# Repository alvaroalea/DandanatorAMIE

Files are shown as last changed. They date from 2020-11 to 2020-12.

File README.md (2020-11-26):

# ZX Dandanator with Multiply Addon all in one
## Alea's Multiply Integrated Edition

UNDER LICENSE Creative Commons Attribution-NonCommercial-ShareAlike 4.0 International (CC BY-NC-SA 4.0)
- If you remix, transform, or build upon the material, you must distribute your contributions under the same license as the original.
- You may not use the material for commercial purposes.
- You must give appropriate credit, provide a link to the license, and indicate if changes were made. You may do so in any reasonable manner, but not in any way that suggests the licensor endorses you or your use.

Original Design by Dandare, mad3001 and OverClk

PCB Design of the V2.1AMIE edition by AlvaroAlea

This is a project to integrate in only one PCB (well, in three) the ZX Dandanator Cartridge for ZX Spectrum and the Multiply Addon.

Check the father projects:

http://www.dandare.es

https://github.com/mad3001/Multiply

Your can download the programs need for programing GAL & PIC on this links

## Features

* 512Kb of flash memory for zero seconds load of games with a fancy menu

* microSD Card Slot for load of snapshots (Z80 and SNA) and tape files, also to program the flash memory

* microUSB conection for transfer flash memory from PC to Dandanator

* A multi-protocol Joystick conector that provide a Kempston Interface and allow to use any atari, SJS, or megadrive joystick with any ZX Spectrum

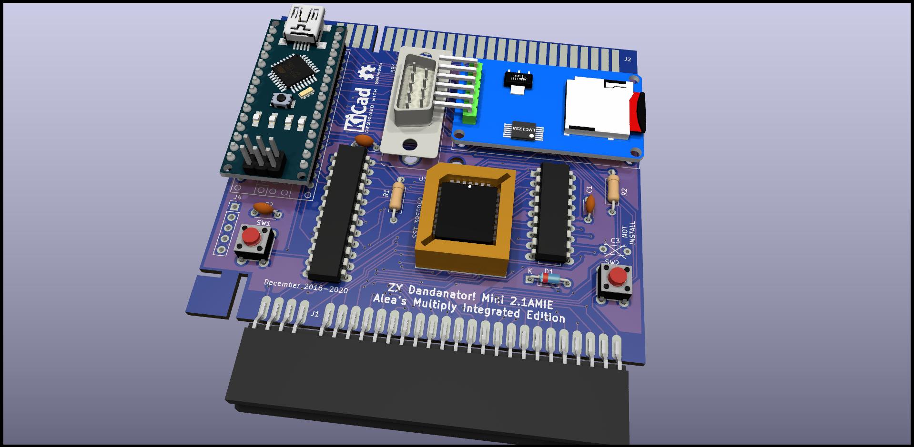
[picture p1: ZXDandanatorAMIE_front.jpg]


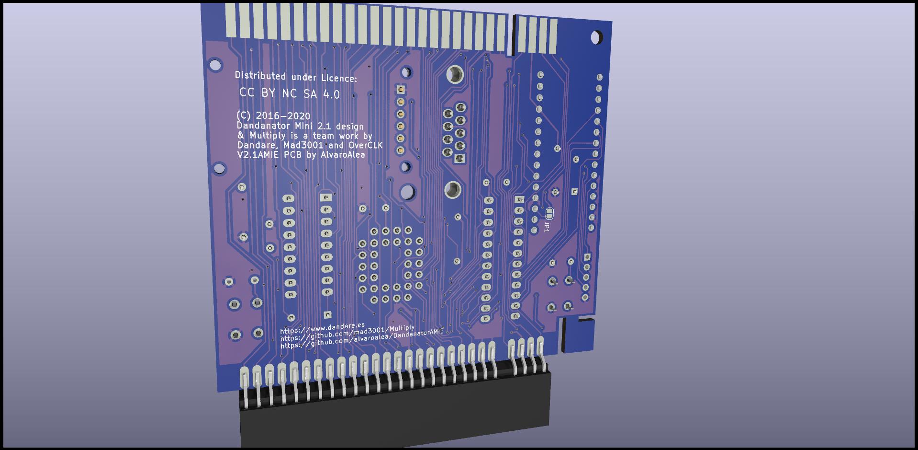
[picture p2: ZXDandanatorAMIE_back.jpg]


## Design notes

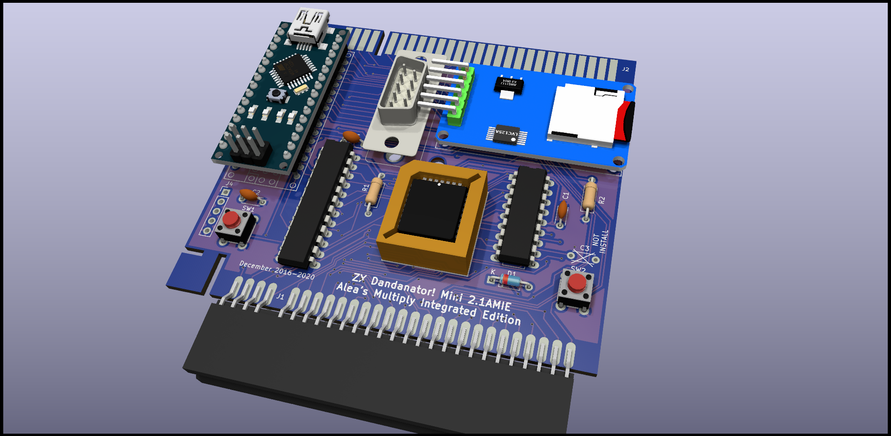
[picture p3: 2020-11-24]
ZX Dandanator Mini 2.1b.png

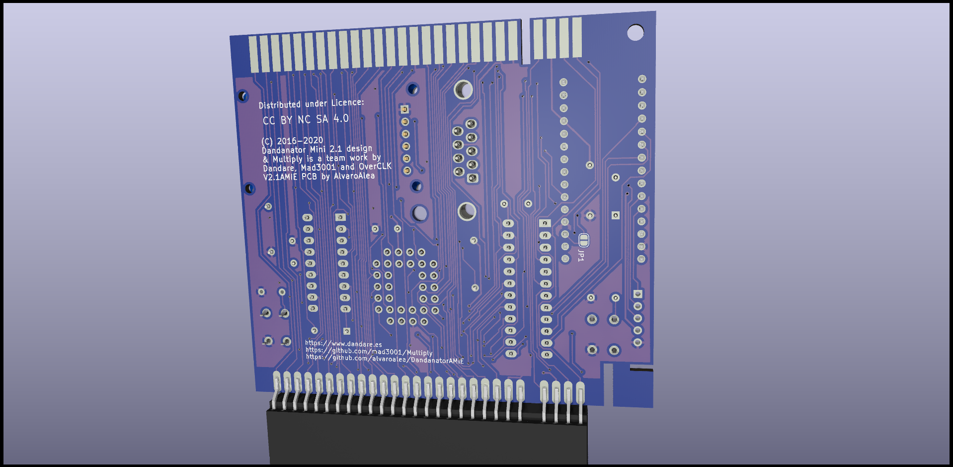
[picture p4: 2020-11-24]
ZX Dandanator Mini 2.1b_back.png

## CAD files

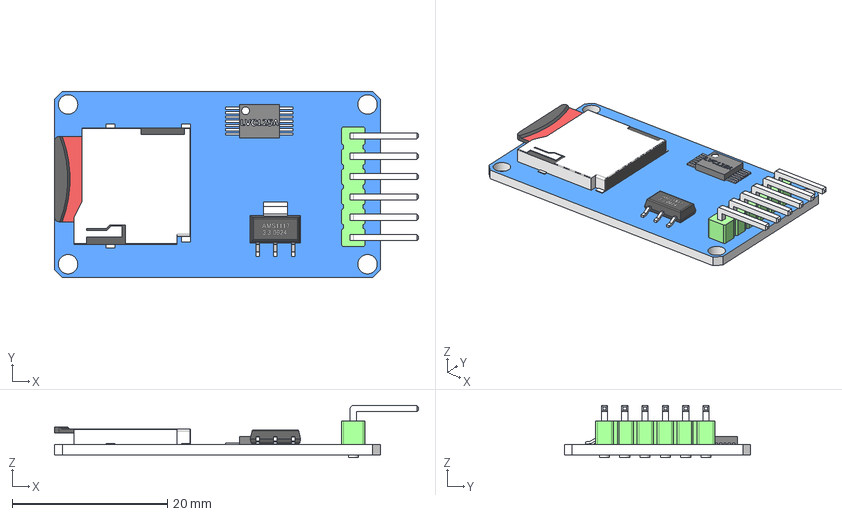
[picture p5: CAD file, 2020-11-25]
MicroSD Reader Assembly.stp
46.9 x 24.0 x 6.70 mm
sdreader
AMS1117
card sd

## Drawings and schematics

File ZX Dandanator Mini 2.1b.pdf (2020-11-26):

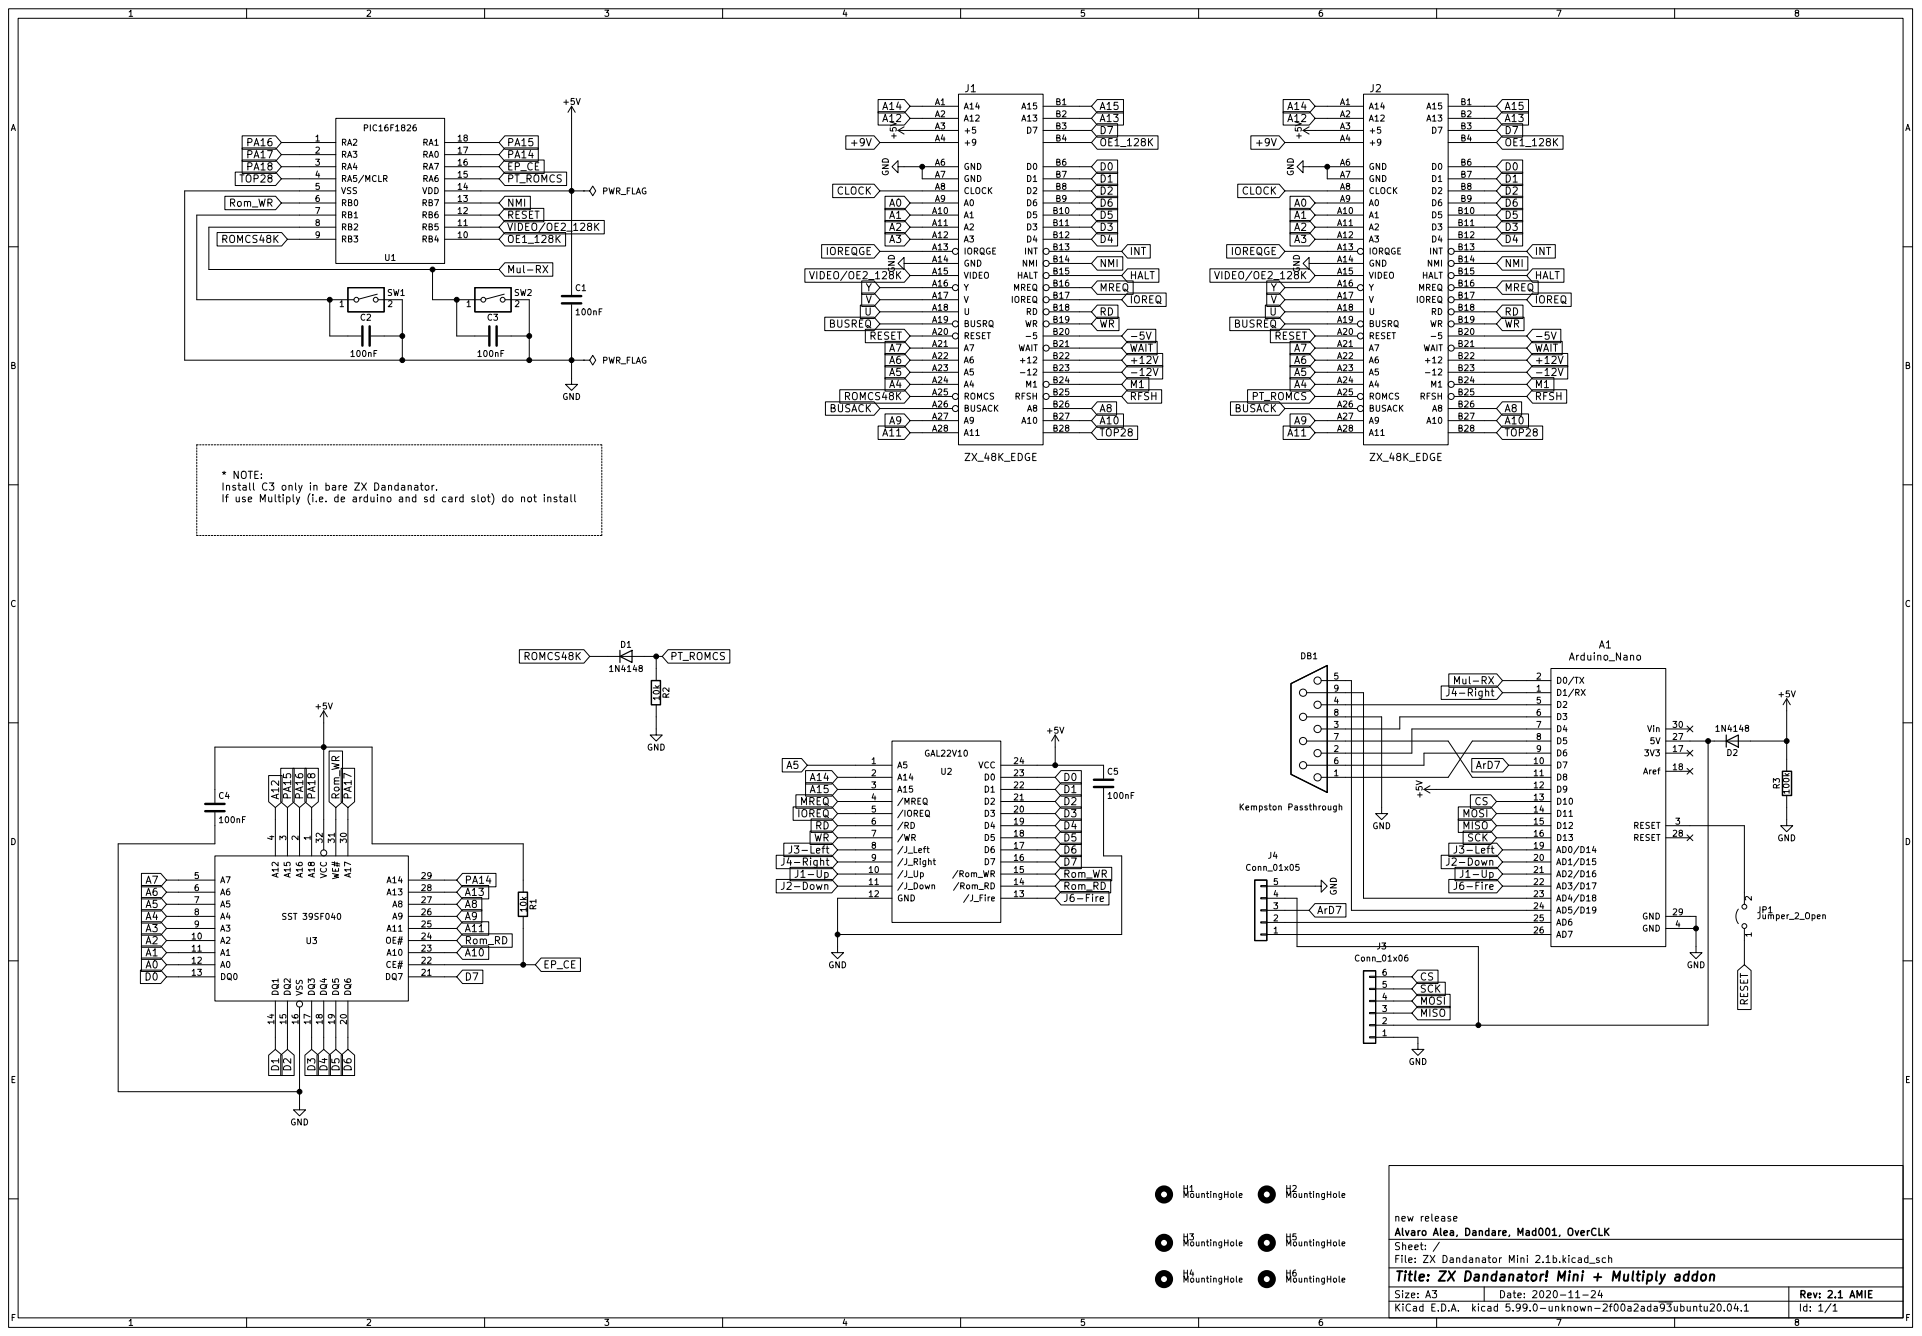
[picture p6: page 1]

4 U3 SST 39SF040 +5V GND GND GND 10k R1 GND +5V

* NOTE:
Install C3 only in bare ZX Dandanator.
If use Multiply (i.e. de arduino and sd card slot) do not install

new release
File: ZX Dandanator Mini 2.1b.kicad_sch Sheet: / Alvaro Alea, Dandare, Mad001, OverCLK

Id: 1/1 Title: ZX Dandanator! Mini + Multiply addon

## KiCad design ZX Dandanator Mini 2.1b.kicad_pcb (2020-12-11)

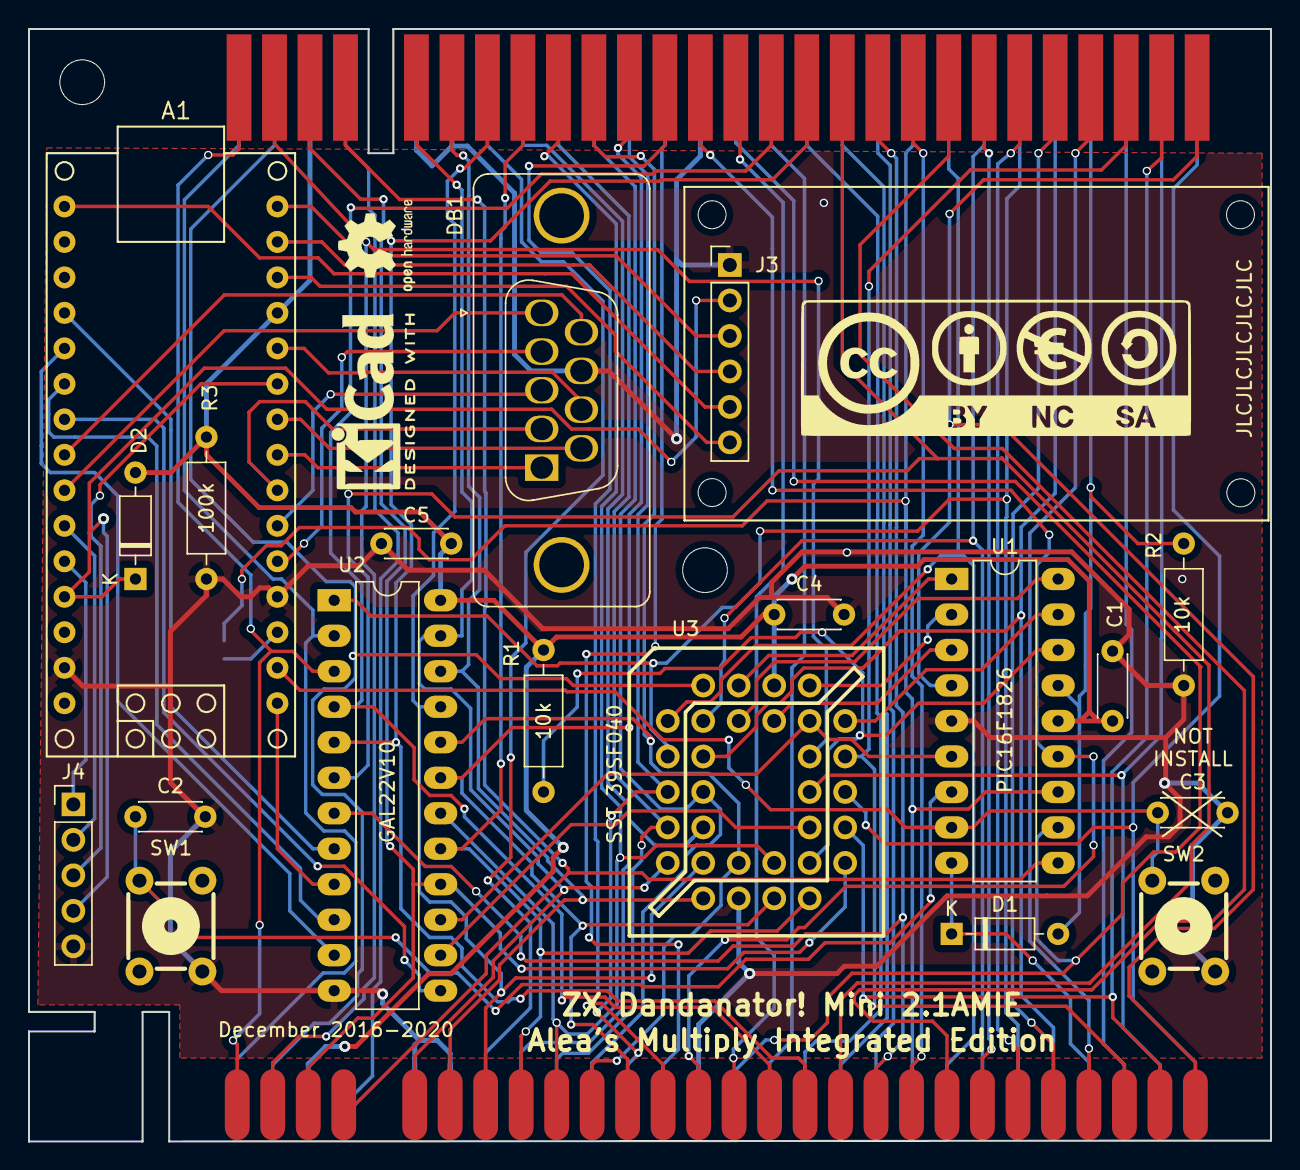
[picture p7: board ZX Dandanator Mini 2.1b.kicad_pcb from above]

Board: 2 copper layers, 88.9 x 79.6 mm, 28 parts (1 on the bottom side), 85 nets.

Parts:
A1: Arduino_Nano; arduino_nano
C1, C2, C3, C4, C5: 100nf; C_Disc_D4.3mm_W1.9mm_P5.00mm
D1, D2: 1n4148; D_DO-35_SOD27_P7.62mm_Horizontal
DB1: Kempston Passthrough; DSUB-9_Female_Vertical_P2.77x2.84mm_MountingHoles
H1, H2: MountingHole; MountingHole_3.2mm_M3_ISO7380
H3, H4, H5, H6: MountingHole; MountingHole_2mm
J1: ZX_48K_EDGE; ZX_CONN
J2: ZX_48K_EDGE; ZX_BUS
J3: Conn_01x06; PinHeader_1x06_P2.54mm_Vertical
J4: Conn_01x05; PinHeader_1x05_P2.54mm_Vertical
JP1: Jumper_2_Open; SolderJumper-2_P1.3mm_Open_RoundedPad1.0x1.5mm
R1, R2: 10k; R_Axial_DIN0207_L6.3mm_D2.5mm_P10.16mm_Horizontal
R3: 100k; R_Axial_DIN0207_L6.3mm_D2.5mm_P10.16mm_Horizontal
SW1, SW2: SW_PUSH; PCB_PUSH
U1: PIC16F1826; DIP-18_W7.62mm_LongPads
U2: GAL22V10; DIP-24_W7.62mm_LongPads
U3: SST 39SF040; plcc32_pth-skt

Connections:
+5V: A1.12 (D9), C1.1, C4.1, C5.1, D2.2 (A), J1.A3 (+5), J2.A3 (+5), R1.1, R3.1, U1.14 (VDD), U2.24 (VCC), U3.32 (VCC)
+9V: J1.A4 (+9), J2.A4 (+9)
+12V: J1.B22 (+12), J2.B22 (+12)
-5V: J1.B20 (-5), J2.B20 (-5)
-12V: J1.B23 (-12), J2.B23 (-12)
A0: J1.A9 (A0), J2.A9 (A0), U3.12 (A0)
A1: J1.A10 (A1), J2.A10 (A1), U3.11 (A1)
A2: J1.A11 (A2), J2.A11 (A2), U3.10 (A2)
A3: J1.A12 (A3), J2.A12 (A3), U3.9 (A3)
A4: J1.A24 (A4), J2.A24 (A4), U3.8 (A4)
A5: J1.A23 (A5), J2.A23 (A5), U2.1 (A5), U3.7 (A5)
A6: J1.A22 (A6), J2.A22 (A6), U3.6 (A6)
A7: J1.A21 (A7), J2.A21 (A7), U3.5 (A7)
A8: J1.B26 (A8), J2.B26 (A8), U3.27 (A8)
A9: J1.A27 (A9), J2.A27 (A9), U3.26 (A9)
A10: J1.B27 (A10), J2.B27 (A10), U3.23 (A10)
A11: J1.A28 (A11), J2.A28 (A11), U3.25 (A11)
A12: J1.A2 (A12), J2.A2 (A12), U3.4 (A12)
A13: J1.B2 (A13), J2.B2 (A13), U3.28 (A13)
A14: J1.A1 (A14), J2.A1 (A14), U2.2 (A14)
A15: J1.B1 (A15), J2.B1 (A15), U2.3 (A15)
ArD7: A1.10 (D7), J4.3
BUSACK: J1.A26 (BUSACK), J2.A26 (BUSACK)
BUSREQ: J1.A19 (BUSRQ), J2.A19 (BUSRQ)
CLOCK: J1.A8 (CLOCK), J2.A8 (CLOCK)
CS: A1.13 (D10), J3.6
D0: J1.B6 (D0), J2.B6 (D0), U2.23 (D0), U3.13 (DQ0)
D1: J1.B7 (D1), J2.B7 (D1), U2.22 (D1), U3.14 (DQ1)
D2: J1.B8 (D2), J2.B8 (D2), U2.21 (D2), U3.15 (DQ2)
D3: J1.B11 (D3), J2.B11 (D3), U2.20 (D3), U3.17 (DQ3)
D4: J1.B12 (D4), J2.B12 (D4), U2.19 (D4), U3.18 (DQ4)
D5: J1.B10 (D5), J2.B10 (D5), U2.18 (D5), U3.19 (DQ5)
D6: J1.B9 (D6), J2.B9 (D6), U2.17 (D6), U3.20 (DQ6)
D7: J1.B3 (D7), J2.B3 (D7), U2.16 (D7), U3.21 (DQ7)
EP_CE: R1.2, U1.16 (RA7), U3.22 (CE#)
GND: A1.4 (GND), A1.29 (GND), C1.2, C2.2, C3.2, C4.2, C5.2, DB1.8, J1.A6 (GND), J1.A7 (GND), J1.A14 (GND), J2.A6 (GND), J2.A7 (GND), J2.A14 (GND), J3.1, J4.5, R2.2, R3.2, SW1.2, SW2.2, U1.5 (VSS), U2.12 (GND), U3.16 (VSS)
HALT: J1.B15 (HALT), J2.B15 (HALT)
INT: J1.B13 (INT), J2.B13 (INT)
IOREQ: J1.B17 (IOREQ), J2.B17 (IOREQ), U2.5 (/IOREQ)
IOREQGE: J1.A13 (IORQGE), J2.A13 (IORQGE)
J1-Up: A1.21 (AD2/D16), U2.10 (/J_Up)
J2-Down: A1.20 (AD1/D15), U2.11 (/J_Down)
J3-Left: A1.19 (AD0/D14), U2.8 (/J_Left)
J4-Right: A1.1 (D1/RX), U2.9 (/J_Right)
J6-Fire: A1.22 (AD3/D17), U2.13 (/J_Fire)
M1: J1.B24 (M1), J2.B24 (M1)
MISO: A1.15 (D12), J3.3
MOSI: A1.14 (D11), J3.4
MREQ: J1.B16 (MREQ), J2.B16 (MREQ), U2.4 (/MREQ)
Mul-RX: A1.2 (D0/TX), C3.1, SW2.1, U1.8 (RB2)
NMI: J1.B14 (NMI), J2.B14 (NMI), U1.13 (RB7)
unnamed: A1.3 (RESET), JP1.2 (B)
unnamed: A1.5 (D2), DB1.4
unnamed: A1.6 (D3), DB1.3
unnamed: A1.7 (D4), DB1.2
unnamed: A1.8 (D5), DB1.1
unnamed: A1.9 (D6), DB1.6
unnamed: A1.11 (D8), DB1.7
unnamed: A1.23 (AD4/D18), DB1.9
unnamed: A1.24 (AD5/D19), DB1.5
unnamed: A1.25 (AD6), J4.2
unnamed: A1.26 (AD7), J4.1
unnamed: A1.27 (5V), D2.1 (K), J3.2, J4.4
unnamed: C2.1, SW1.1, U1.7 (RB1)
OE1_128K: J1.B4, J2.B4, U1.10 (RB4)
PA14: U1.17 (RA0), U3.29 (A14)
PA15: U1.18 (RA1), U3.3 (A15)
PA16: U1.1 (RA2), U3.2 (A16)
PA17: U1.2 (RA3), U3.30 (A17)
PA18: U1.3 (RA4), U3.1 (A18)
PT_ROMCS: D1.2 (A), J2.A25 (ROMCS), R2.1, U1.15 (RA6)
RD: J1.B18 (RD), J2.B18 (RD), U2.6 (/RD)
RESET: J1.A20 (RESET), J2.A20 (RESET), JP1.1 (A), U1.12 (RB6)
RFSH: J1.B25 (RFSH), J2.B25 (RFSH)
ROMCS48K: D1.1 (K), J1.A25 (ROMCS), U1.9 (RB3)
Rom_RD: U2.14 (/Rom_RD), U3.24 (OE#)
Rom_WR: U1.6 (RB0), U2.15 (/Rom_WR), U3.31 (WE#)
SCK: A1.16 (D13), J3.5
TOP28: J1.B28, J2.B28, U1.4 (RA5/MCLR)
U: J1.A18 (U), J2.A18 (U)
V: J1.A17 (V), J2.A17 (V)
VIDEO/OE2_128K: J1.A15 (VIDEO), J2.A15 (VIDEO), U1.11 (RB5)
WAIT: J1.B21 (WAIT), J2.B21 (WAIT)
WR: J1.B19 (WR), J2.B19 (WR), U2.7 (/WR)
Y: J1.A16 (Y), J2.A16 (Y)

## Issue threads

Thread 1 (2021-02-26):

Schematics and Kicad

liveboxandy, 2021-02-26:
Are there any schematics, Kicad files, etc for this project?  Would like to be able to change the design to use a 3V3 uSD module rather than the current 5V with a builtin 3V3 regulator.

All I can find are some files for the ZX Dandanator Mini v2.1b

liveboxandy, 2021-02-26:
Found out why. It's been created with a nightly build of Kicad 5.99 which won't open in the stable version 5.1.9
and there doesn't appear to be a way to convert them to the stable version or downgrade them. Looks liike I need to install a nightly build to open the files.

liveboxandy, 2021-04-21:
Downloaded nightly build and opened OK

Closed 2021-04-21.

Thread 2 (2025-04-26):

DandanatorAMIE not seeing multiply

oO-cozy-Oo, 2025-04-26:
Thank you Alvaro Alea for a great version of the Dandanator,Just completed this build and all works fine in the menu loads up and i can play the selected roms that i put on in the rom generator, but when i select the SD loader option is says "no multiply decteded"???
I can update via the usb cable from my pc to the Nano (com3) in the rom generator programe, and all updated ok.

Thank you again
Rich

alvaroalea, 2025-05-10:
Be aware that "multiply" is and add-on to dandanator that is conected to the joystick port of the original dandanator.
Mi work is only to join both in the same PCB.
If dandanator say that do not detect multiply this is because it can not see the arduino micro conected to the "joystick port".

So I will check that you have programmed correctly the arduino and that the solder are correct, if you used a socket that all pins are in the socket, etc, etc...

Also, please, be aware that the rom generator, if I remember correctly only write the EEPROM of the dandanator (using the arduino as passthrought) you need to  program the arduino with the correct hex file using a separate program in order to be recognized as "multiply" but also to be able to use the joystick of the interface.

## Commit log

2020-11-25 upload project
    [ZX Dandanator Mini 2.1b-B_Cu.gbr, ZX Dandanator Mini 2.1b-B_Mask.gbr, ZX Dandanator Mini 2.1b-Edge_Cuts.gbr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]
2020-11-25 3d model
    [MicroSD Reader Assembly.stp]
2020-11-26 small fix
    [ZX Dandanator Mini 2.1b-B_Cu.gbr, ZX Dandanator Mini 2.1b-B_Mask.gbr, ZX Dandanator Mini 2.1b-Edge_Cuts.gbr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]

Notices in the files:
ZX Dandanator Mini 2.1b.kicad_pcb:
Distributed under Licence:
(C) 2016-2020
